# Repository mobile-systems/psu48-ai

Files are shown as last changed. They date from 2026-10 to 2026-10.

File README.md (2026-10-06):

# PSU48-800 — БП 220 В AC → 48 В DC, 800 Вт

Проект импульсного блока питания (PFC + LLC), разрабатывается в KiCad 10.

- `JOURNAL.md` — инженерный журнал (этапы, решения, изменения).
- `docs/SPEC.md` — техническое задание.
- `docs/DESIGN.md` — расчёт топологии.
- `kicad/` — проект KiCad (схема, плата, библиотеки).
- `tools/` — скрипты генерации и проверки (Python, bundled с KiCad).
- `production/` — производственные файлы (Gerber, drill, BOM, CPL, PDF).

Сборка проекта (генерация схемы/платы) и выпуск — см. журнал, этапы работ.

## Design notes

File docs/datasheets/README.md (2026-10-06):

# Справочные материалы (datasheets)

Руководства/даташиты по компонентам, использованные при проектировании PSU48-800.
Скачаны для локального хранения (сторонние ресурсы st.com/alldatasheet могут блокировать
прямой доступ или менять адреса).

| Файл | Компонент | Издатель | Источник |
|---|---|---|---|
| `UCC24624.pdf` | 2-channel LLC synchronous-rectifier controller (SOIC-8, VD≤230 В) | TI | https://www.ti.com/lit/ds/symlink/ucc24624.pdf |
| `UCC24610.pdf` | SR controller (не применён: VD max 50 В) | TI | https://www.ti.com/lit/ds/symlink/ucc24610.pdf |
| `UC3854.pdf` | Average-current-mode PFC controller | TI (UC family) | https://www.ti.com/lit/ds/symlink/uc3854.pdf |
| `L6599A_farnell.pdf` | Improved high-voltage resonant (LLC) controller; тот же TSOP-16, что L6599 | ST, копия Farnell | https://www.farnell.com/datasheets/1876813.pdf (оригинал: https://www.st.com/resource/en/datasheet/l6599a.pdf — st.com блокирует скачивание из скриптов) |
| `TinySwitch4_TNY284-290.pdf` | TNY290P offline switcher (PDIP-8C) | Power Integrations | https://www.power.com/sites/default/files/documents/tinyswitch-4_family_datasheet.pdf |
| `INA181.pdf` | Current-sense amplifier (шунт OCP, gain 20/50/100/200) | TI | https://www.ti.com/lit/ds/symlink/ina181.pdf |
| `LM393.pdf` / `LM393-N.pdf` | Dual comparator (пороги FAULT/PG) | TI | https://www.ti.com/lit/ds/symlink/lm393.pdf , https://www.ti.com/lit/ds/symlink/lm393-n.pdf |

Примечания:
- `BSC070N10NS3` (SR-переключатели, Infineon) не сохранён: infineon.com отдаёт HTML вместо PDF при автоматическом скачивании; исходники брать вручную с https://www.infineon.com/dgdl/Infineon-BSC070N10NS3-DS-v02_09-EN.pdf.
- L6599A — улучшенная ревизия L6599 с тем же назначением (резонансный полумост, 50% скважность), тот же вывод (SO-16); в схеме используется символ `Regulator_Controller:L6599`.

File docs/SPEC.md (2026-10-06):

# Техническое задание — PSU48-800

| Параметр | Значение |
|---|---|
| Входное напряжение | 176…264 В AC, 50/60 Гц (номинал 220 В) |
| Выходное напряжение | 48,0 В DC ±3 % (46,6…49,4 В) |
| Выходной ток / мощность | 0…16,7 А / 800 Вт |
| КПД | ≥ 93 % при 220 В, полной нагрузке |
| Коэффициент мощности | ≥ 0,99 при 220 В |
| THD входного тока | < 10 % |
| Пульсации выхода | ≤ 1 % (≤ 480 мВ п-п) |
| Время сохранения выхода | ≥ 20 мс при 800 Вт |
| Шина PFC | 400 В ±10 В |
| Напряжение гальванической развязки | вход — выход ≥ 3,75 кВ (усиленная изоляция, II класс) |
| Защиты | OCP, OVP, SCP (автостарт), UVLO, перегрев, разряд шины |
| Сигналы | PG (Power Good), Remote ON/OFF (TTL/сухой контакт) |
| Охлаждение | принудительное, вентилятор 12 В 60×25 мм |
| Габариты платы | 280 × 90 мм |
| Высота сборки | ≤ 40 мм (в сборе с корпусом) |
| Установка | 4 отверстия Ø3,2 под М3 |

## Состав выпуска
- Схема (иерархия, 5 листов) — PDF.
- Печатная плата — Gerber (RS-274X), Excellon drill, карта положений (CPL), BOM.
- Спецификация BOM с производителями/артикулами.

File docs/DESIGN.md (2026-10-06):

# Расчёт топологии PSU48-800

## 1. Исходные данные и баланс мощности
- Pout = 800 Вт, Vout = 48 В, Iout = 16,67 А.
- Принимаем η = 0,93 на полной нагрузке → Pin ≈ 860 Вт; ток сети при 220 В ≈ 3,9 А.
- Мощность потерь ≈ 60 Вт (PFC ≈ 20 Вт, LLC ≈ 25 Вт, выпрямитель/фильтры ≈ 15 Вт).

## 2. Входной выпрямитель и фильтр
- Предохранитель T6,3 А/250 В, MOV 14D471K, NTC 5 Ом/5 А с реле шунта (Omron G2R-1-E 12 В).
- Фильтр: X2 0,47 мкФ → дроссель общего режима 10 мГн/5 А → Y2 2×2,2 нФ → X2 0,22 мкФ.
- Мост GBU10J (10 А/600 В).
- Шина: 3 × 330 мкФ/450 В (Ø35×35, low-ESR) = 990 мкФ.
  - Запас энергии от 400 В до 340 В: E = ½·C·(400²−340²) = 22 Дж → t = 22 / 860 ≈ 25 мс ≥ 20 мс ✓.

## 3. Boost PFC (CCM, 65 кГц)
- Входной средний ток 3,9 А, пик 5,5 А; пульсации тока ΔI = 25 % Ipk = 1,4 А.
- L = Vin·D/(f·ΔI), при Vin = 311 В, D = 1 − 311/400 = 0,22:
  L = 311·0,22/(65000·1,4) ≈ 0,75 мГн → **750 мкГн**, ток насыщения ≥ 7 А (размагничивание + пульсации).
- Транзистор IPP60R099C7 (600 В, 99 мОм, TO-247): P ≈ I²·R·D/3 + переключение ≈ 8 Вт (+ потери диода).
- Диод SiC IDH10S60C (600 В, 10 А) — без обратного восстановления.
- Шунт тока UC3854: 2 × 0,22 Ом 5 Вт параллельно = 0,11 Ом; пик-напряжение 0,6 В.
- Делитель VSENSE: 400 В → 6 В (3 МОм + 51 кОм), фильтр 100 нФ.
- Осциллятор UC3854: Rt = 6,8 кОм? → f ≈ 65 кГц (Rosc = 659/Vosc... берётся 6,8 кОм), Ct = 3,3 нФ.
- Ограничение пускового тока, плавный пуск: Css = 100 нФ.

## 4. LLC полумост (преобразователь DC/DC)
### Преобразование
- Шина 400 В, полумост → амплитуда на первичке ±200 В.
- Трансформатор: Np : Ns(половина) = 4 : 1, выводы: первичка 40 витков (лitz 2×0,1), вторичка 2 × 10 витков (шинка), центральный отвод.
- Vsec(половина) = 200/4 = 50 В → после синхронного выпрямления ≈ 48 В при M = 0,96…1,0 (работа у резонанса).

### Резонансный контур
- Нагрузка, отражённая: Rac ≈ V1(осн)² / Ppri; V1(осн) = (4/π)·200/√2 = 180 В, Ppri ≈ 860 Вт → Rac ≈ 38 Ом.
- Выбираем: **Lr = 40 мкГн, Cr = 82 нФ (3 × 27 нФ/630 В параллельно)** → f0 = 1/(2π√(Lr·Cr)) ≈ **88 кГц**.
- Характерное сопротивление Zr = √(Lr/Cr) = 22 Ом → Q = Zr/Rac ≈ 0,58 (в допустимом диапазоне 0,3…0,7).
- Индуктивность намагничивания Lm = 4 × Lr ≈ 160 мкГн (зазор по расчёту на EE35).
- Диапазон регулировки: fmax ≈ 130 кГц (холостой ход), fmin ≈ 50 кГц (старт/перегрузка), M(fmin) ≈ 1,3.
- Транзисторы полумоста: 2 × IPP60R099C7 (как в PFC — унификация).
- Резонансный конденсатор: ток ≈ 4,3 А действ., 3 × 27 нФ → 1,4 А на конденсатор ✓.

### Синхронный выпрямитель и выход
- 2 ключа по схеме с центральным отводом, каждый — 2 × BSC070N10NS3 (100 В, 7 мОм, TDSON-8) параллельно; I²R ≈ 0,5 Вт на ключ.
- Управление — 1 × UCC24624 (двухканальный SR-контроллер для LLC, чувствительные VD-выводы на 230 В), по напряжению сток-исток.
- Выходной фильтр: 4 × 470 мкФ/63 В (105 °C, low-ESR) + керамика 10 × 10 мкФ/100 В; расчёт пульсаций при f = 176 кГц на выходе ≈ 30 мВ п-п ✓.
- TVS 1,5SMC58A, разрядный/преднагрузочный резистор 68 кОм 5 Вт.

### Управление
- Регулировка по напряжению: TL431 (опорное 2,5 В, делитель 48 В → 2,5 В) → оптрон PC817 → вход FB L6599.
- Токовая защита: шунт 3 мОм на возврате вторички → INA181A2 (×50) → компаратор LM393 → SD L6599 (порог ≈ 19 А).
- OVP: компаратор LM393 (опора 5,0 В на делителе выхода) → SD.

## 5. Вспомогательный источник
- Flyback на TNY290PG от шины 400 В (схема с общим возвратом), EE16, 65 кГц.
- Обмотки: +15 В / 0,6 А (первичная обмотка — питание UC3854, L6599, реле, вентилятор через L7812 → 12 В) и изолированная +15 В / 0,3 А (вторичная обмотка — питание UCC24624).
- Обратная связь по PC817 (цикл по напряжению + ограничение тока обмотки).

## 6. Тепловой баланс и охлаждение
- ≈ 60 Вт рассеивания: PFC-транзистор ≈ 8 Вт, LLC ≈ 10 Вт, диод PFC ≈ 5 Вт, SR ≈ 3 Вт, мост/шунты/EC ≈ 15 Вт, трансформаторы ≈ 15 Вт.
- Решение: линейка TO-247 PFC/LLC на общем алюминиевом профиле (высота ≤ 25 мм), обдув вентилятором 60×25 мм с торца корпуса; площадь радиатора ≈ 150 см² при ΔT ≈ 40 К достаточно.

## 7. Размещение на плате (концепция)
Слева направо: вход AC + фильтр → мост + шина (верхний ряд конденсаторов) → PFC (дроссель, ключ, диод) → полумост LLC + резонанс → трансформер EE35 → вторичный выпрямитель + выходные конденсаторы → выходные клеммы. Вспомогательный flyback и логика управления — вдоль нижнего края. Силовой ток идёт слева направо по «полосе» шириной ≥ 8 мм, возврат — нижняя медная заливка.

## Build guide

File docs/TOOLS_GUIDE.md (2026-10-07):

# Руководство по инструментам (tools/) PSU48

Скрипты в `tools/` генерируют и проверяют проект PSU48 (KiCad 10) "из текста":
схема, библиотека, плата, размещение и (экспериментально) трассировка.
Часть кода универсальна и пригодна для других независимых проектов; часть —
жёстко привязана к конфигурации `tools/sch_data.py`. Ниже — реестр, порядок
работы, способ переноса на новый проект и ограничения.

---

## 1. Окружение

- Windows, KiCad **10.0** (`C:/Program Files/KiCad/10.0`).
- Python берётся из дистрибутива KiCad:
  `"C:/Program Files/KiCad/10.0/bin/python.exe"` (свой системный Python не требуется).
- Все скрипты запускаются из каталога `tools/` (они импортируют друг друга через
  относительные имена).
- CLI KiCad: `"C:/Program Files/KiCad/10.0/bin/kicad-cli.exe"`.
- Единица хранения данных — **S-выражение** (S-expr). Парсинг/сериализация
  полностью вынесены в `sexp.py`.

---

## 2. Реестр скриптов

| Файл | Роль | Переиспользуемость |
|---|---|---|
| `sexp.py` | Парсер/сериализатор S-expr (KiCad-совместимый), helpers `find/findall/unq/Q/num` | Полностью универсален |
| `kilib.py` | Чтение `.kicad_sym`/`.pretty/*.kicad_mod`, геометрия выводов, встраивание symbol в `lib_symbols` | Универсален (слой библиотек KiCad) |
| `sch_data.py` | **Конфигурация проекта**: листы, элементы, сети, клеммы питания, отверстия | Только psu48 (заменить целиком) |
| `schgen.py` | Генератор `.kicad_sch` (корень + листы) из `sch_data`; пишет `.kicad_pro` | Ядро универсально, питается конфигом |
| `verify.py` | Экспорт netlist (`kicad-cli sch export netlist`) + сверка с `sch_data` | Универсален (нужен конфиг) |
| `qa.py` | Проверка корпусов: совпадение падов с пинами схемы, геометрия | Полезен для проверки библиотек |
| `mklib.py` | Сборка проектной библиотеки `kicad/psu48_lib.kicad_sym` и `kicad/psu48.pretty/*` | Настройка под проект (списки пар) |
| `pcbgen.py` | Генерация `.kicad_pcb` (280×90, корпуса из библиотек, назначение сетей) + размещение | Каркас универсален, геометрия/якоря — под psu48 |
| `router.py` | Экспериментальная автотрассировка (2 слоя, A*, треки/виа) — **β** | Ядро универсально; стили шин/порядок — конфиг |
| `dump_pins.py` | Отладка: списки пинов символов `Device:R` и пр. | Универсальный отладочный |
| `peek_symbol.py` | Отладка: печать фрагмента `.kicad_sym` | Универсальный отладочный |

---

## 3. Порядок работы (workflow)

Оптимальный порядок для нового проекта:

1. **Библиотеки** — `mklib.py` (если используются свои символы/корпуса).
2. **Схема** — `schgen.py`: пишет `kicad/<project>.kicad_sch`,
   `kicad/<sheet>.kicad_sch`, `kicad/<project>.kicad_pro`.
3. **Проверка схемы** — `verify.py` (сверка pin↔net против конфига) и
   `kicad-cli sch erc <root>.kicad_sch -o out.rpt`.
4. **Контроль корпусов** — `qa.py`.
5. **Плата + размещение** — `pcbgen.py`: пишет `kicad/<project>.kicad_pcb`.
6. **DRC посадочных** — `kicad-cli pcb drc ... --severity-all`.
7. **Трассировка (экспериментально)** — `router.py` (дописывает треки/виа в ту же плату).
8. **Финальный DRC**, затем вывод Gerber/Drill/BOM/CPL/PDF через `kicad-cli`.

Типовые команды (из `tools/`):

```bash
PY="C:/Program Files/KiCad/10.0/bin/python.exe"
"$PY" mklib.py
"$PY" schgen.py
"$PY" verify.py
"$PY" qa.py
"$PY" pcbgen.py
"$PY" router.py            # β
CLI="C:/Program Files/KiCad/10.0/bin/kicad-cli.exe"
"$CLI" pcb drc ../kicad/psu48.kicad_pcb -o C:/tmp/pcbdrc.rpt --severity-all
```

---

## 4. Адаптация под новый проект

Минимально заменяется конфиг `sch_data.py`; имя проекта и параметры
разбросаны в заголовках скриптов.

### 4.1 `sch_data.py`
- `PROJECT`, `ROOT_TITLE`, `REV`, `DATE` — имя и шапка.
- `POWER_TERMS` — глобальные (клеммные) сети.
- `SHEETS` — список листов с элементами `{"id", "title", "entries": [{ref,
  fp, val, nets, at, bb, pinmap, ...}]}`. Это **расширяемая спецификация**
  схемы: по ней schgen рисует лист, verify сверяет, pcbgen ставит корпуса.
- `ROOT_HOLES` — монтажные отверстия.
- Геометрия размещения (`X0/Y0/COL_GAP/...`) — разметка листа.

### 4.2 `pcbgen.py`
- `BOARD_W`, `BOARD_H` — габариты платы.
- `PREFER`, `GROUP_ANCHOR`, `REGION_BOARD`, `HOLE_POS`, `MARGIN`, `PACK_STEP` —
  стратегия размещения (якоря структур/листов, допуски).
- `fp_path()` — откуда брать `.kicad_mod` (проектная `psu48.pretty` или
  стандартная библиотека KiCad).
- `net_name()` — правила "локальная/глобальная" сеть в имени платы.

### 4.3 `router.py`
- `net_style(net)` — ширина/класс по имени сети (OUT/HV/PWR/SIG).
- Порядок трассировки `route_key()` (класс → число падов).
- Параметры через env (см. ниже).

---

## 5. Ограничения

### Общие
- Скрипты рассчитаны на одну плату/один уровень иерархии схемы; символы
  только из `.kicad_sym` (KiCad 10 S-expr), не Symbol-Library-Table v7.
- Никакой GUI-проверки: корректность подтверждается только `kicad-cli
  drc/erc` + `verify.py`.
- Формат вывода заточен под **KiCad 10** (см. §6).

### Роутер (`router.py`) — экспериментальный
- Сетка трассировки — **0.2 мм**; минимальный эффективный зазор —
  `ROUTE_CL≥0.2`. Из-за квантования невозможно провести трассу к выводу
  SOIC-шага 1.27 мм с чистым DRC — зазор между соседними контактными
  площадками закрывается кольцами запаса. Сигнальные сети в плотных
  кластерах могут оставаться неразведёнными.
- Только **2 сигнальных слоя**, A* с 4-соседними переходами, виа 1.2/0.6 мм.
- Многослойная связность падает при большом числе падов у сети (манхэттенский
  поиск по сетке — не промышленный роутер; для высокой заполненности нужен
  fanout/эскейп-роутинг).
- Ядро **не проверяет** реальный DRC сам; контроль — внешний `kicad-cli pcb drc`.
- Режимы через переменные окружения:
  - `PSU_STEP` — шаг сетки, мм (по умолчанию 0.2; 0.1 — заметно медленнее);
  - `PSU_SIGW` — ширина сигнальных трасс (0.3);
  - `PSU_CL` — зазор трассировки (0.25);
  - `PSU_RCAP` — множитель узости колец запаса (0..1; 0 открывает каналы и
    может нарушать DRC).
- Текущее состояние: большинство силовых сетей проводятся; сигнальные
  сети между выводами мелких корпусов — предмет доработки.

### `pcbgen.py`
- Размещение строится структурно (функциональные группы листов), а не
  по соединениям; auto-оптимизатора нет.
- Сети "склеиваются" по правилам `net_sheets_map()`: локальные сети листа
  получают префикс `Лист/Сеть` — решение специфично для иерархии проекта.

### `schgen.py`
- Переиспользуемо как движок "S-expr → лист", но разметка листа
  (`PAPER_LIMITS`, перенос при `Overflow`) отражает стиль psu48.

---

## 6. Особенности KiCad 10, зафиксированные в проекте

Эти детали важны при генерации любых файлов для KiCad 10:

- **Треки и виа** в `.kicad_pcb` используют атрибут `(uuid "...")`, а **не**
  `(tstamp ...)` — иначе "Failed to load board: Expecting ')'".
- Внутри `(segment ...)`/`(via ...)` сеть пишется **только кодом** без имени:
  `(net 4)`, а не `(net 4 "+48V")` (в узлах сетей платы — наоборот, и код, и имя).
- Порядок критичных узлов платы: `(kicad_pcb (version) (generator)
  (general) (paper) (title_block) (layers ...) (setup ...) (net ...)`*
  затем корпуса, затем треки/виа, в конце `(embedded_fonts no)`.
- Чисел с ведущими пробелами не допускается; числа печатаются через
  `sexp.num()` (максимум 6 знаков, без хвостовых нулей).
- Кодировка файлов — UTF-8, переводы строк `\n` (не `\r\n`).
- `sexp.py` сохраняет точный исходный текст атомов: строки остаются в
  кавычках (`Raw`), поэтому round-trip идентичен исходнику.

---

## 7. Как понять и изменить внутреннюю модель

- **Узел** в `sexp.py` — обычный Python-список: `["kicad_pcb",
  ["layers", ...]]`. `dumps()` сам добавляет скобки и отступы.
- `Raw("...")` — "сырое" значение (например, `'"F.Cu"'`), его нельзя
  редактировать как строку Python.
- Порядок и обработку данных смотри: `sch_data.py` (спека) →
  `schgen.py`/`verify.py` (схема) → `pcbgen.py` (плата) → `router.py`
  (трассы). Каждый следующий потребляет предыдущий через общий конфиг.

---

## 8. Итог для переноса

| Что нужно | Где править |
|---|---|
| Имя проекта / шапка | `sch_data.py` |
| Список листов и элементов | `sch_data.py` (секции `SHEETS`) |
| Глобальные сети | `sch_data.py` (`POWER_TERMS`) |
| Монтажные отверстия | `sch_data.py` (`ROOT_HOLES`) + `pcbgen.HOLE_POS` |
| Габариты платы | `pcbgen.BOARD_W/BOARD_H` |
| Стратегия размещения | `pcbgen.PREFER/GROUP_ANCHOR/REGION_BOARD` |
| Ширины/приоритеты трасс | `router.net_style()/route_key()` |
| Зажим точности роутера | env `PSU_STEP/PSU_SIGW/PSU_CL/PSU_RCAP` |

Универсальные блоки (`sexp.py`, `kilib.py`, ядро `schgen/verify/pcbgen/router`)
берутся без изменений; проектная спецификация целиком сосредоточена в
`sch_data.py` + нескольких таблицах констант в заголовках генераторов.

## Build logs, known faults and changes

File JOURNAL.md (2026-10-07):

# Инженерный журнал проекта «PSU48-800»

**Изделие:** импульсный блок питания 220 В AC → 48 В DC, 800 Вт
**Формат:** проект KiCad 10, ПП 280 × 90 мм, высота корпуса 40 мм
**Ведётся:** с 2026-10-06

---

## 2026-10-06 — Этап 0. Инициализация

### Окружение
- Windows 11 Pro, KiCad 10.0.6 (`C:\Program Files\KiCad\10.0\bin\kicad-cli.exe`).
- git 2.56.0, Python 3.11.5 (в комплекте KiCad — используется для скриптов генерации).
- Репозиторий git инициализирован в корне проекта; все изменения коммитятся с пояснениями.
- Рабочая папка: `C:\Users\alexa\workspace\psu48-ai`. Все артефакты — только в ней.

### Принятая архитектура (вариант, выбранный сразу)

Для 800 Вт с высоким КПД и PF ≥ 0,99 применяется классическая двухступенчатая схема:

1. **Входной тракт**: предохранитель, MOV, NTC + реле шунта, двух-каскадный симметричный фильтр помех (X2/Y2, дроссель общего режима), мостовой выпрямитель.
2. **PFC (коррекция коэффициента мощности)** — boost в непрерывном режиме (CCM), 65 кГц, выходное напряжение шины **400 В**. Контроллер — **UC3854GN**. Мощные элементы: IPP60R099C7 (600 В, 99 мОм), диод-шоттки SiC IDH10S60C, дроссель 750 мкГн/5,5 А.
3. **DC/DC** — резонансный **LLC полумост**, ~88 кГц резонанс, трансформатор EE35 с раздельной резонансной индуктивностью, синхронный выпрямитель на вторичной стороне (4 × BSC070N10NS3, контроллеры UCC24610 ×2), выход 48 В / 16,7 А. Контроллер — **L6599D**.
4. **Вспомогательный источник** — flyback на TNY290PG от шины 400 В: +15 В (первичная обмотка, питание контроллеров и вентилятора через L7812) и изолированная обмотка +15 В (вторичная сторона, питание SR-контроллеров).
5. **Защиты и сигнализация**: OCP (шунт 3 мОм + INA181 + LM393), OVP (TL431/компаратор), UVLO, PG, Remote ON/OFF, разряд шины.

### Компромиссы, ограничения корпуса 40 мм
- Максимальная высота элементов — 35 мм (конденсаторы шины Ø35, трансформатор EE35 ≈ 30 мм).
- Теплоотвод: 800 Вт при η ≈ 93 % → ≈ 60 Вт рассеивания; заложено охлаждение принудительное (вентилятор 60×25 в корпусе), мощные транзисторы — в линейку с общим алюминиевым радиатором/полосой.
- Плата 280 × 90 мм, 2 слоя, медная заливка под силовые цепи (толщина меди 2 oz в силовых зонах — рекомендация для технолога).

### План работ (этапы, каждый — отдельный коммит)
1. Документация: ТЗ, расчёт топологии, журнал (this commit).
2. Средства генерации: сепаратор s-expr, загрузчик библиотек символов, генератор иерархической схемы.
3. Схема: 5 листов + собственная библиотека символов, проверка ERC и сверка нетлиста со спецификацией соединений.
4. Библиотеки footprint + генерация PCB: контур 280×90, размещение.
5. Маршрутизация, зоны заливки, DRC.
6. Выпуск производственных файлов: Gerber/Drill/BOM/CPL/PDF.

### Идеи / заметки
- Все соединения в схеме задаются декларативно (карта «вывод → имя цепи»), генератор расставляет символы и подписи. Это позволяет скриптом **проверять нетлист против задуманной карты** — защита от ошибок «метка не попала на вывод».
- Глобальные метки — для цепей, выходящих за границы листа; локальные — внутри листа.
- PWR_FLAG на всех силовых цепях для чистого ERC.
- Резонансный контур LLC: Lr = 40 мкГн, Cr = 82 нФ (3×27 нФ), Lm ≈ 160 мкГн, f0 ≈ 88 кГц, Q ≈ 0,6 — расчёт подробно в `docs/DESIGN.md`.

---

---

## 2026-10-06 — Этап 3. Схема: 5 листов, генератор, ERC, сверка нетлиста

### Реализовано
- `tools/sch_data.py` — декларативная спецификация: 5 листов (`01_ac_input`…`05_ctrl`), все компоненты с картами «вывод → цепь», константы раскладки (STUB=5.08, BEND=2.54, ROW_GAP=5.08, COL_GAP=20.32, GAP=10.16, X0/Y0), POWER_TERMS.
- `tools/schgen.py` — генератор файлов `.kicad_sch` (root A4 + листы A3/A2 при переполнении) и `psu48.kicad_pro`; терминаторы-штабели, L-изгибы, локальные/глобальные метки, PWR_FLAG, `no_connect`, instance-пути.
- `tools/verify.py` — сверка нетлиста `kicad-cli sch export netlist` против карт `sch_data` (445 выводов / 97 цепей — PASS).
- `tools/qa.py` — геометрический контроль текстов/символов по файлу схемы.

### Ошибки, найденные доводкой и исправленные
- **Sub-symbol naming**: символы, использующие `(extends …)` (напр. `Comparator:LM393` ← `LM2903`), при внедрении в `lib_symbols` должны переименовывать подстили в `<имя>_<unit>_<style>`; иначе KiCad не грузит файл («Failed to load schematic»). Исправлено в `kilib.merge_derived`.
- **Wires**: KiCad допускает ТОЛЬКО двухточечные `(wire (pts …))`; трёхточечные (изгиб) приводят к ошибке загрузки. Изгиб теперь — два сегмента.
- **Дубли UUID**: у двух PWR_FLAG на одном листе совпадали ключи `sheet:None:1` → дублировались `(uuid …)` символа и пинов. Ключи флагов переведены на счётчик `flg`.
- **`circle` в символьной графике**: KiCad 10 хранит `(radius …)` вместо `(end …)` — `bbox_of` теперь понимает оба.
- **Footprint**: `Connector_TerminalBlock:TerminalBlock_bornier-2` не существует в KiCad 10 (библиотека переименована) → `TerminalBlock:TerminalBlock_MaiXu_MX126-5.0-02P_1x02_P5.00mm`.
- **ERC вредные 4 → 0**: 
  - `SR_SYNC` (UCC24610 pin 1, Input) не имел драйвера — по даташиту при неиспользуемом синхросинтезе пин подключают к GND; U302/U303 pin 1 → GND48 (*сверить с datasheet*).
  - остальные (пороговые входы компараторов — не Pins, а internal, сеть лишь из пассивов) — рассмотрено, свойств нет.
- **Overflow A3→A2**: ширина строки вычислялась до правки условия переноса (не учитывала `wr` и межэлементный зазор) — исправлено; `03_llc` закономерно занял A2.

### Проверки (все PASS)
1. Каждый лист и root независимо открываются `kicad-cli sch export netlist` (0 компонентов не потеряно; листы грузятся и отдельно).
2. `kicad-cli sch erc` по всему проекту: **0 ошибок, 0 предупреждений**.
3. `verify.py`: нетлист совпадает со спецификацией на 445 выводах / 97 цепях.
4. `qa.py`: наложений текстов/символов не выявлено (одно касание двух меток одной цепи `HN` с зазором 0.27 мм — косметика).

### Решения и допущения (сверить с datasheet)
- UCC24610: SYNC н/и → GND48; работа в режиме удержания времени (TON), без внешней синхронизации.
- L6599 RFMIN: оптопара регулятора параллельно R_min (f увеличивается при FB) — взято из классической топологии; полярность подтвердить по datasheet.
- ERC-фильтры «не включены»: нетлист — прямое зеркало спецификации.

### Компоненты листа (итог)
`01_ac_input` 18, `02_pfc` 43, `03_llc` 66, `04_aux` 27, `05_ctrl` 26, root-крепеж H1–H4 (MountingHole 3.2 mm M3) — всего ~180 поз. + символы питания.

### Уточнения по даташитам (websearch-верификация; правки внесены)
- **L6599 RFmin (pin 4)** — даташит ST подтверждает топологию: пин отдаёт точное опорное 2 В; три ветви: RFmin→GND (мин. частота), RFmax→коллектор оптрона (макс. частота), R-C серия Css/Rss (мягкий старт). Чем выше ток с пина, тем выше частота → при росте Vout частота повышается, Vout падает — полярность ОС подтверждена.
  - R309 20k (RFmin) ✓; добавлен **R328 4.7k (RFmax)** последовательно коллектору U306 → RFmin; **R308 100k** переведён с некорректной цепи на мягкий старт (LLC_CSS→LLC_FB).
  - Пин 2 и 13 L6599 — **N.C.**; удалены R308-старая ветка и C303 (намеренная «цепь задержки» на N.C. — ошибка).
- **UCC24610 НЕ применим при 48 В**: VD (сток-SR) номинально максимум 50 В; вторичная обмотка LLC на 48 В даёт ~2×48=96 В на стоке SR. Также SYNC, «подвязанный к GND», удерживал бы GATE выключенным (SR не работал бы).
  → **замена на UCC24624 (TI)**: двухканальный SR-контроллер LLC, VD до 230 В, reference-design 48 В/550 Вт (UCC256302+UCC24624). Один корпус вместо двух. Питание VDD (+15VS, <24.75 В — прямое подключение), REG байпас 2.2 мкФ, VSS к GND48 («не оставлять открытым»).
  - Символ `psu48_lib:UCC24624` (SOIC-8, 1=VG1 2=PGND 3=REG 4=VD1 5=VSS 6=VD2 7=VDD 8=VG2) добавлен в mklib.
  - Схема: G_SR1/G_SR2 (по 2 FET), VD1/VD2=SEC_A/SEC_B, удалены U303/R314/R315/C314 (артефакты UCC24610 TON/SYNC).
- Повторная проверка после правок: verify 433 вывода OK, ERC 0/0, qa чисто (одно касание меток HN с зазором 0.27 мм — косметика).

### Справочные материалы (docs/datasheets/)
- Пользователь попросил хранить найденные PDF/manuals в `docs/`. Скачано 8 даташитов:
  UCC24624, UCC24610, UC3854, L6599A (копия Farnell — st.com блокирует скриптовое скачивание),
  TinySwitch-4 TNY284–290, INA181, LM393/LM393-N. Список и источники — `docs/datasheets/README.md`.
- BSC070N10NS3 (Infineon) не скачан автоматически (отдаёт HTML); ссылка в README.

---

## 2026-10-07 — Этап 4 (подготовка PCB): генерация платы, размещение, DRC

### Найден и устранён реальный дефект схемы (коллизия локальных меток)
- Проверка имён локальных сетей по листам (для PCB-нетлиста) выявила **ошибочное склеивание меток между листами**:
  - `SEC_A` — на листе **03** (вторичка LLC: T301, Q310–Q313, U302) и на листе **04** (вторичка aux‑flyback: T401 pin5, D404 pin2) — через метку «SEC_A» вторичная 48‑В обмотка LLC электрически соединялась бы с вторичной 15‑В обмоткой aux. **→ переименовано в `AUX_SEC`.**
  - `LED_A` — на листе **03** (катод оптрона ОС U306) и на листе **05** (индикатор LED501) — через метку «LED_A» катод LED16 соединялся бы с током индикатора (несогласованная ветвление ОС). **→ переименовано в `STATUS_LED`.**
- Проверка после правки: локальных коллизий нет; кросс‑листовые цепи (кроме POWER_TERMS) только намеренные: `ISENSE_48` (03/05, шунт→INA181), `LLC_LINE` (03/05, оптропарная ОС MPF), `PFC_EN` (02→03). verify **433 вывода / 99 цепей OK**, ERC **0/0**, qa — без новых наложений.

### `tools/pcbgen.py` — генератор `kicad/psu48.kicad_pcb` (KiCad 10)
- kicad-cli **не умеет создавать PCB и импортировать нетлист** (команды только drc/export/import/render/upgrade), поэтому плата пишется S-выражением: заголовок `(version 20260206)`, слои/setup — по эталону пустой платы из `pcbnew.CreateEmptyBoard()`, таблица `(net 0 "«)(net N "имя")`, футиринты встраиваются из `.kicad_mod` с картинкой/падами/нетом по номеру пина, контур 280×90 — `gr_line` на Edge.Cuts, H1–H4 по углам.
- **Имена сетей в PCB полностью совпадают с нетлистом**: локальные → `SHEET/NAME` (как в netlist/verify.py), глобальные/POWER_TERMS → короткое имя.
- **Размещение**: площадь корпусов ≈ 14 300 мм² при доске 25 200 мм² (Σ с учётом корпусов, а не только пад — иначе коротят). Упаковщик: крупные первыми (меньше фрагментации), у каждой позиции «якорь» функциональной группы → сначала точный слот, затем спиральный поиск вокруг якоря, затем общий свип; монтажные отверстия — препятствия. Ошибка «no free spot» при данном наборе не возникает.

### Ключевые баги геометрии, найденные через DRC
1. **Форма `(at x y ROT)`: поворот в KiCad — по часовой стрелке.** Мой первый `abs_rect` крутил против часовой → каждые J301/J501 (ROT 90) резервировали не ту область → короткие цепи «HN×LED_A», «GND48×PFC_VS» и пр. Исправлено: `rot = −radians(...)`.
2. **Ориджин футиринта ≠ центру bbox.** Пады многих THT-корпусов (TerminalBlock, PinHeader, DIP) живут далеко от центра симметрии; упаковщик резервировал «центрированную» рамку → пады выкалывались за её край → реальные короткие цепи. Теперь считается истинный `abs_rect` от локального `(min, max)` с доворотом углов.
3. **`fp_circle`**: у KiCad окружность — `(center)/(end)` (точка на окружности), а не радиус; прошлая версия читала радиус как координату end → у отверстий/корпусов courtyard по Y недооценивался (у H1 3.45×1.6 вместо 6.9×6.9). Исправлено через `hypot(end−center)`.
4. **`fp_text`**: бокс текста — не точка, а ≈ полразмера шрифта вокруг якоря (+0.15) → меньше ложных «Silkscreen clipped by solder mask».

### DRC (kicad-cli pcb drc)
- **0 ошибок уровня copper**: нет коротких замыканий, нарушений зазора 0.2 мм, hole‑clearance, маски. Пас.
- Остались **предупреждения silk** (≈199 silk_overlap + ≈126 silk_over_copper) — наложени графики шелкографии соседних корпусов/текста; косметика, не влияет на электрику.
- 335 «unconnected pads» — вывода с цепями но без меди (маршрутизация на этапе 5) + неиспользуемые пины (запасные контакты реле K101, QFN‑thermal, механические). Нормально до разводки.
- lib_footprint_mismatch появлялся **только у повёрнутых на 90°** разъёмов J301/J501 — артефакт сверки этой версии KiCad; повороты сняты (ROT 0) → предупреждений нет. Геометрия корпусов идентична библиотеке (проверено структурным diff).
- 2×`MountingHole` в углах учтены как препятствия; контур и края чистые.

### Заметки на следующий этап (маршрутизация)
- Проверить соответствие посадочного места/нумерации выводов у малогабаритных символов (U503 TL431). Проверить сети полей: 2 слоя, заливки GND/PGND_OUT/VBUS400/+48V.
- Из предупреждений DRC отфильтровать silk (footer «ignore»); добиваться 0 ошибок — достигнуто.

---

## 2026-10-07 — Этап 5 (начало): автотрассировка `tools/router.py`

### Статус
Экспериментальная. Плата в рабочем дереве содержит результат последнего прогона
(712 сегментов / 595 виа); файл **валиден и грузится KiCad**, но DRC **чистым не
является** (см. «Проверки»). Основные проблемы диагностированы; финальный
рефакторинг модели занятости **начат и не завершён** (код в `router.py`
компилируется, но с промежуточными остатками `trackF/trackB`).

### Валидность кикадовского вывода (решено)
- KiCad 10 в `(segment …)`/`(via …)` принимает сеть **только кодом без имени**
  `(net 66)`, а не `(net 4 "+48V")`, и атрибут **`(uuid …)`, а не `(tstamp …)`** —
  иначе `Failed to load board: Expecting ')'`. Оба фикса в `router.py`
  (эталон синтаксиса — demo-плата CM5_MINIMA + файл от pcbnew + пустая плата
  `pcbnew.CreateEmptyBoard()`). После правок файл читается, DRC запускается.

### Устранено по ходу доводки
- Убран `carve`, эрозировавший занятость ранее проложенных широких треков →
  короткие замыкания.
- Порядок разводки: `pending` был `set` (терялся приоритет — +48V разводились
  раньше сигнальных → низкая разводимость); теперь цикл по упорядоченному списку.
- Инфлейт падов был не зависим от ширины трассы (0.4 мм) → широкие трассы
  налезали на чужие пады; введены ширино-зависимые маски `masks[r]` и
  виа-маска `vm_all` (пады + пояс воль via).
- `prep_route` (зануление собственных падов в маске), `own_reuse` (повторное
  использование своих проводников в многосвязных сетях).

### Результаты прогонов (routed / DRC)
- `PSU_RCAP=0.0` (узкие кольца): **86/89** сетей разведено (+48V не лезет,
  `02_pfc/PFC_MULT`, `03_llc/LLC_DIS`, `04_aux/AUX_SEC`) — но узкие кольца
  нарушают зазоры.
- `PSU_RCAP=1.0` (запас): ~59/63 — почти все силовые, но сигнальные в
  SMD-кластерах не проходят.
- Последний DRC рабочем дереве (1791): clearance 499, **shorting_items 199**,
  **holes_co_located 199**, **tracks_crossing 143**, unconnected 169, hole_to_hole 95,
  track_dangling 58, copper_sliver 8, + silk (косметика).

### Диагнозы (корни оставшихся ошибок)
1. **`holes_co_located` ≈199** — `split_path` при переходе слоёв генерирует **два
   виа в одной точке**; нужен один `(i,j)` на переход.
2. **shorting / tracks_crossing ≈199** — зазор трасса-трасса считался по своей
   ширине; для разных классов требуется **симметричный парный зазор
   `(wA + wB)/2 + CL`** — иначе узкие трассы пересекают/касаются широких
   (+48V 2.5 мм и др.), даже когда кольца падов валидны.
3. **Квантование сетки 0.2 мм** — SOIC-шаг 1.27 мм: зазор между соседними падами
   закрывается кольцами запаса; сигнальные сети в плотных кластерах не выходят.

### Решение (спроектировано, НЕ реализовано)
Замена `trackF/trackB` на **per-routing-class маски** `tm[cls]` (треки) и
`vm2[cls]` (виа), обновляемые инкрементально при прокладке пути ширины `wl`
для всех классов `w(cls) ≤ wl`: радиус `tm = (w_cls + wl)/2 + CL`,
`vm2 = (VIA_SIZE + wl)/2 + CL`; `mm` (чужие пады) и `own_reuse` сохраняются;
`via_free` дополнительно = `vm_all` и `vm2[live_cls]`. Плюс фикс `split_path`
(один виа на переход). Это должно снять и «пересечения ширин», и «виа на проводнике».

### Параметризация (env)
`PSU_STEP` (0.2), `PSU_SIGW` (0.3), `PSU_CL` (0.25), `PSU_RCAP` (0..1),`PAD_CAP`
не используются — для скан-прогонов по конфигурациям без правки кода.

### Документация
- `docs/TOOLS_GUIDE.md` — руководство по переиспользованию `tools/` в других
  проектах: реестр скриптов, порядок запуска, способ адаптации конфигурации,
  ограничения (роутер β: 2 слоя, сетка 0.2 мм, два уровня A*), особенности
  синтаксиса KiCad 10.

### На следующий этап
- Дописать `tm`/`vm2` + одиночный виа в `split_path`; прогон → DRC; скан
  конфигов (STEP, SIGW, CL, RCAP); создание медных зон GND/GND48/+48V/VBUS400/
  VRECT; проверить U503 (TL431DBV, пады 1/2 без сети — несоответствие
  footprint/symbol).

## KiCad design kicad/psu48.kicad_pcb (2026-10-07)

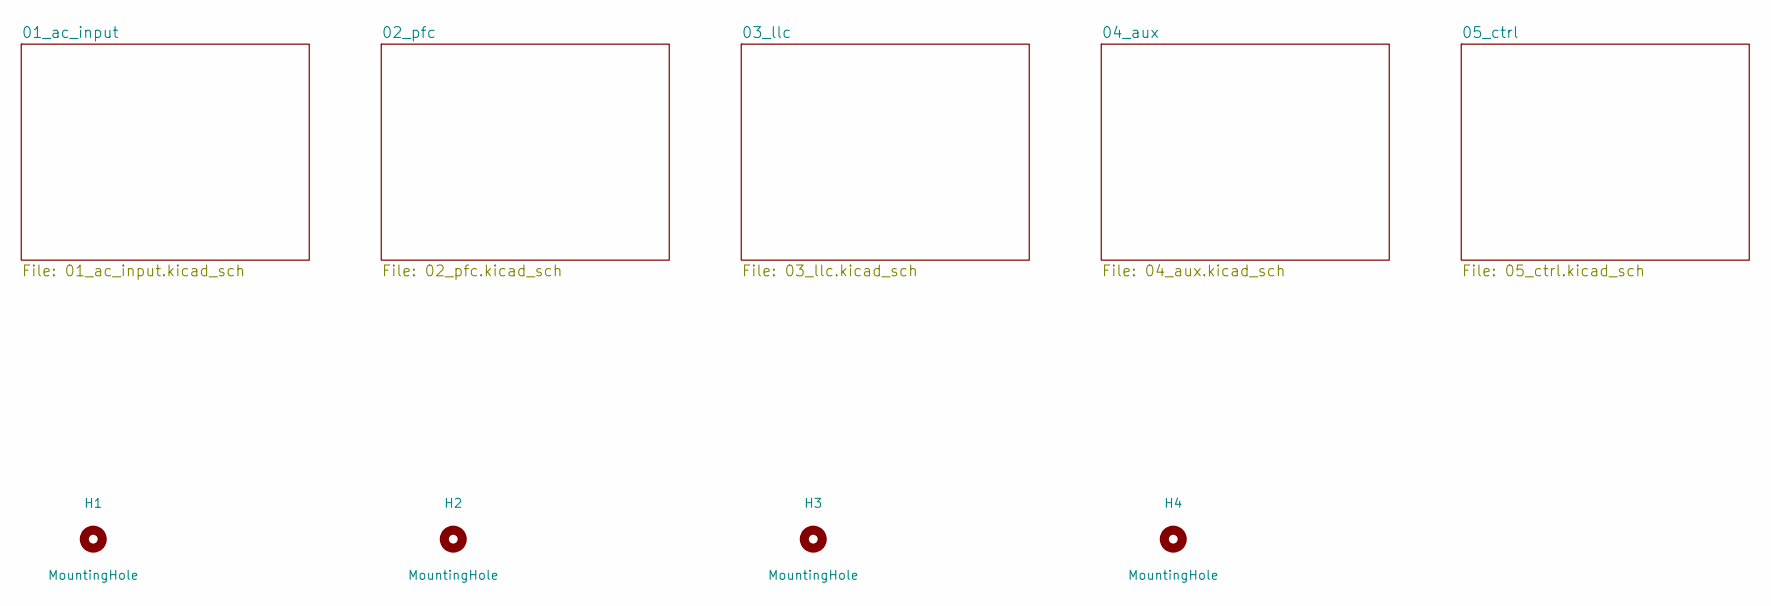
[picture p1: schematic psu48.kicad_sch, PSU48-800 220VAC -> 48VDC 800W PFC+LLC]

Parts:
H1, H2, H3, H4: MountingHole; MountingHole_3.2mm_M3

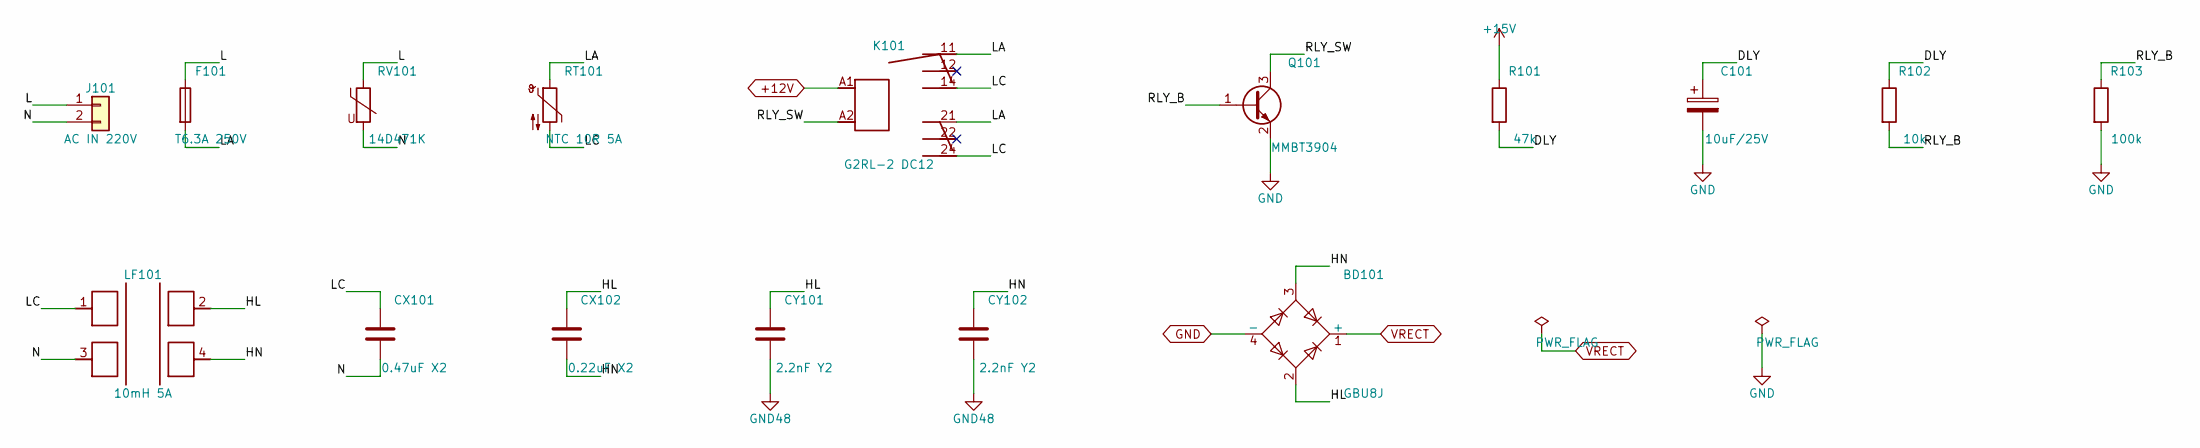
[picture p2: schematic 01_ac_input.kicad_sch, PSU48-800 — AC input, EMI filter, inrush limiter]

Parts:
BD101: GBU8J; Diode_Bridge_Vishay_GBU
C101: 10uF/25V; CP_Radial_D5.0mm_P2.50mm
CX101: 0.47uF X2; C_Rect_L27.0mm_W11.0mm_P22.00mm
CX102: 0.22uF X2; C_Rect_L16.5mm_W5.0mm_P15.00mm_MKT
CY101, CY102: 2.2nF Y2; C_Disc_D10.5mm_W5.0mm_P7.50mm
F101: T6.3A 250V; Fuseholder_Clip-5x20mm_Littelfuse_111_Inline_P20.00x5.00mm_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
J101: AC IN 220V; TerminalBlock_MaiXu_MX126-5.0-02P_1x02_P5.00mm
K101: G2RL-2 DC12; Relay_DPDT_Omron_G2RL-2
LF101: 10mH 5A; CMChoke_25x20_P20x10
Q101: MMBT3904; SOT-23
R101: 47k; R_0805_2012Metric
R102: 10k; R_0805_2012Metric
R103: 100k; R_0805_2012Metric
RT101: NTC 10R 5A; NTC_D11.0mm_P5.00mm
RV101: 14D471K; RV_Disc_D15.5mm_W5.9mm_P7.5mm

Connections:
01_ac_input/DLY: C101.1, R101.2, R102.1
01_ac_input/HL: BD101.2, CX102.1, CY101.1, LF101.2
01_ac_input/HN: BD101.3, CX102.2, CY102.1, LF101.4
01_ac_input/L: F101.1, J101.1, RV101.1
01_ac_input/LA: F101.2, K101.11, K101.21, RT101.1
01_ac_input/LC: CX101.1, K101.14, K101.24, LF101.1, RT101.2
01_ac_input/N: CX101.2, J101.2, LF101.3, RV101.2
01_ac_input/RLY_B: Q101.1 (B), R102.2, R103.1
01_ac_input/RLY_SW: K101.A2, Q101.3 (C)
+12V: K101.A1; also elsewhere on the board
+15V: R101.1; also elsewhere on the board
GND: BD101.4 (-), C101.2, Q101.2 (E), R103.2; also elsewhere on the board
GND48: CY101.2, CY102.2; also elsewhere on the board
VRECT: BD101.1 (+); also elsewhere on the board

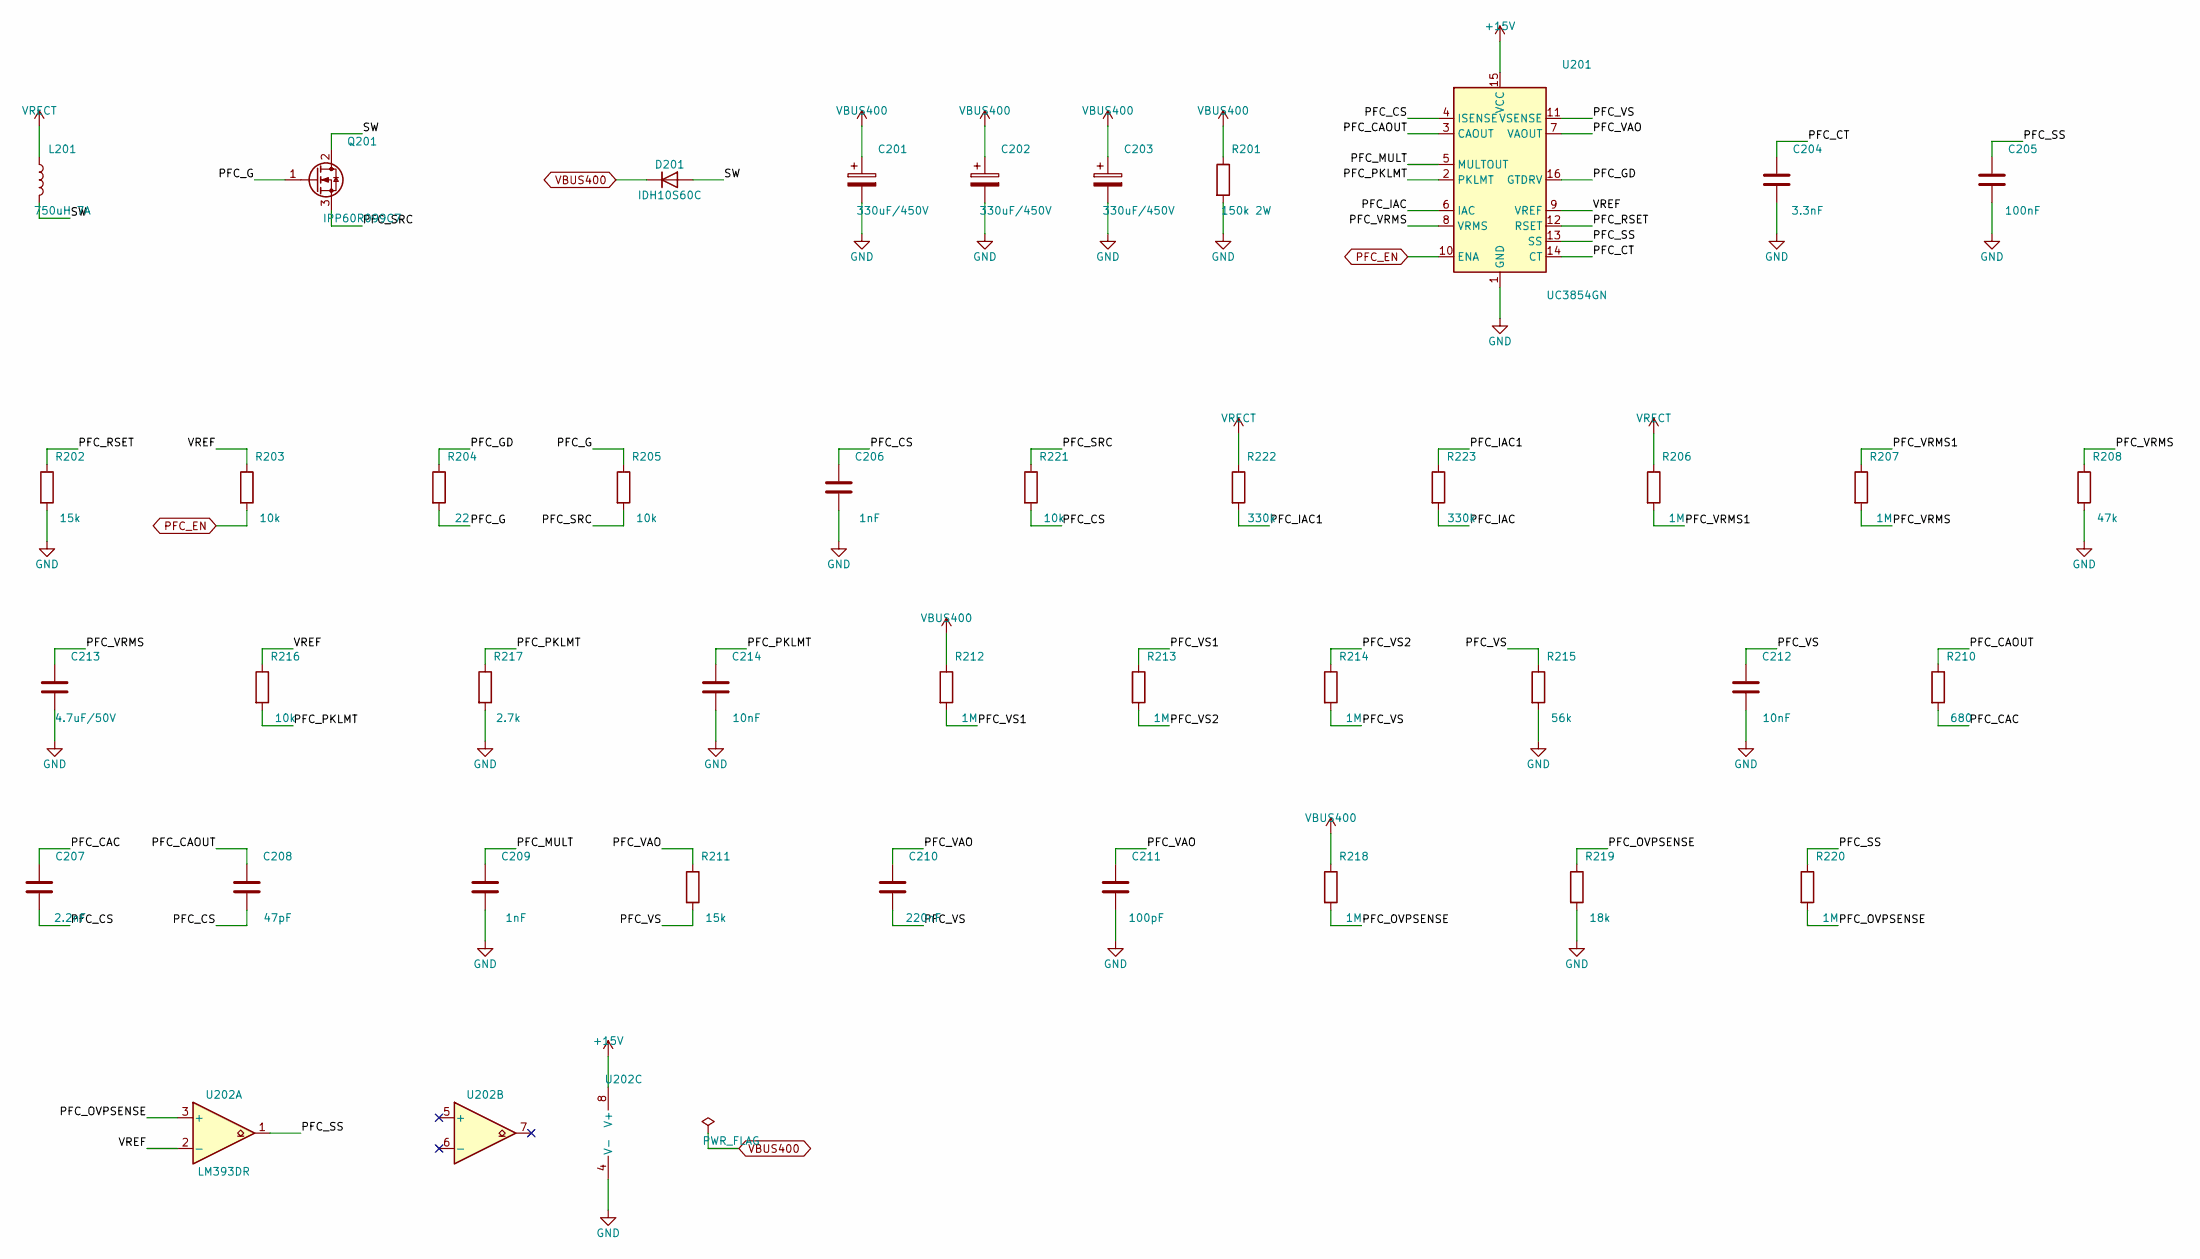
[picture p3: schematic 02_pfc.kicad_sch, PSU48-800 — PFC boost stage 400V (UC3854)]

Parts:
C201, C202, C203: 330uF/450V; CP_Radial_D35.0mm_P10.00mm
C204: 3.3nF; C_0805_2012Metric
C205: 100nF; C_0805_2012Metric
C206, C209: 1nF; C_0805_2012Metric
C207: 2.2nF; C_0805_2012Metric
C208: 47pF; C_0805_2012Metric
C210: 220nF; C_0805_2012Metric
C211: 100pF; C_0805_2012Metric
C212, C214: 10nF; C_0805_2012Metric
C213: 4.7uF/50V; C_1210_3225Metric
D201: IDH10S60C; TO-220-3_Vertical
L201: 750uH 7A; L_THT_D30.0mm_P15.00mm
Q201: IPP60R099C7; TO-220-3_Vertical
R201: 150k 2W; R_Axial_DIN0617_L17.0mm_D6.0mm_P25.40mm_Horizontal
R202, R211: 15k; R_0805_2012Metric
R203, R205, R216, R221: 10k; R_0805_2012Metric
R204: 22; R_0805_2012Metric
R206, R207, R212, R213, R214, R218: 1M; R_1206_3216Metric
R208: 47k; R_0805_2012Metric
R210: 680; R_0805_2012Metric
R215: 56k; R_0805_2012Metric
R217: 2.7k; R_0805_2012Metric
R219: 18k; R_0805_2012Metric
R220: 1M; R_0805_2012Metric
R222, R223: 330k; R_1206_3216Metric
U201: UC3854GN; DIP-16_W7.62mm
U202: LM393DR; SOIC-8_3.9x4.9mm_P1.27mm

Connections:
02_pfc/PFC_CAC: C207.1, R210.2
02_pfc/PFC_CAOUT: C208.1, R210.1, U201.3 (CAOUT)
02_pfc/PFC_CS: C206.1, C207.2, C208.2, R221.2, U201.4 (ISENSE)
02_pfc/PFC_CT: C204.1, U201.14 (CT)
02_pfc/PFC_G: Q201.1 (G), R204.2, R205.1
02_pfc/PFC_GD: R204.1, U201.16 (GTDRV)
02_pfc/PFC_IAC: R223.2, U201.6 (IAC)
02_pfc/PFC_IAC1: R222.2, R223.1
02_pfc/PFC_MULT: C209.1, U201.5 (MULTOUT)
02_pfc/PFC_OVPSENSE: R218.2, R219.1, R220.2, U202.3 (+)
02_pfc/PFC_PKLMT: C214.1, R216.2, R217.1, U201.2 (PKLMT)
02_pfc/PFC_RSET: R202.1, U201.12 (RSET)
02_pfc/PFC_SRC: Q201.3 (S), R205.2, R221.1
02_pfc/PFC_SS: C205.1, R220.1, U201.13 (SS), U202.1
02_pfc/PFC_VAO: C210.1, C211.1, R211.1, U201.7 (VAOUT)
02_pfc/PFC_VRMS: C213.1, R207.2, R208.1, U201.8 (VRMS)
02_pfc/PFC_VRMS1: R206.2, R207.1
02_pfc/PFC_VS: C210.2, C212.1, R211.2, R214.2, R215.1, U201.11 (VSENSE)
02_pfc/PFC_VS1: R212.2, R213.1
02_pfc/PFC_VS2: R213.2, R214.1
02_pfc/SW: D201.2 (A), L201.2, Q201.2 (D)
02_pfc/VREF: R203.1, R216.1, U201.9 (VREF), U202.2 (-)
+15V: U201.15 (VCC), U202.8 (V+); also elsewhere on the board
GND: C201.2, C202.2, C203.2, C204.2, C205.2, C206.2, C209.2, C211.2, C212.2, C213.2, C214.2, R201.2, R202.2, R208.2, R215.2, R217.2, R219.2, U201.1 (GND), U202.4 (V-); also elsewhere on the board
PFC_EN: R203.2, U201.10 (ENA); also elsewhere on the board
VBUS400: C201.1, C202.1, C203.1, D201.1 (K), R201.1, R212.1, R218.1; also elsewhere on the board
VRECT: L201.1, R206.1, R222.1; also elsewhere on the board

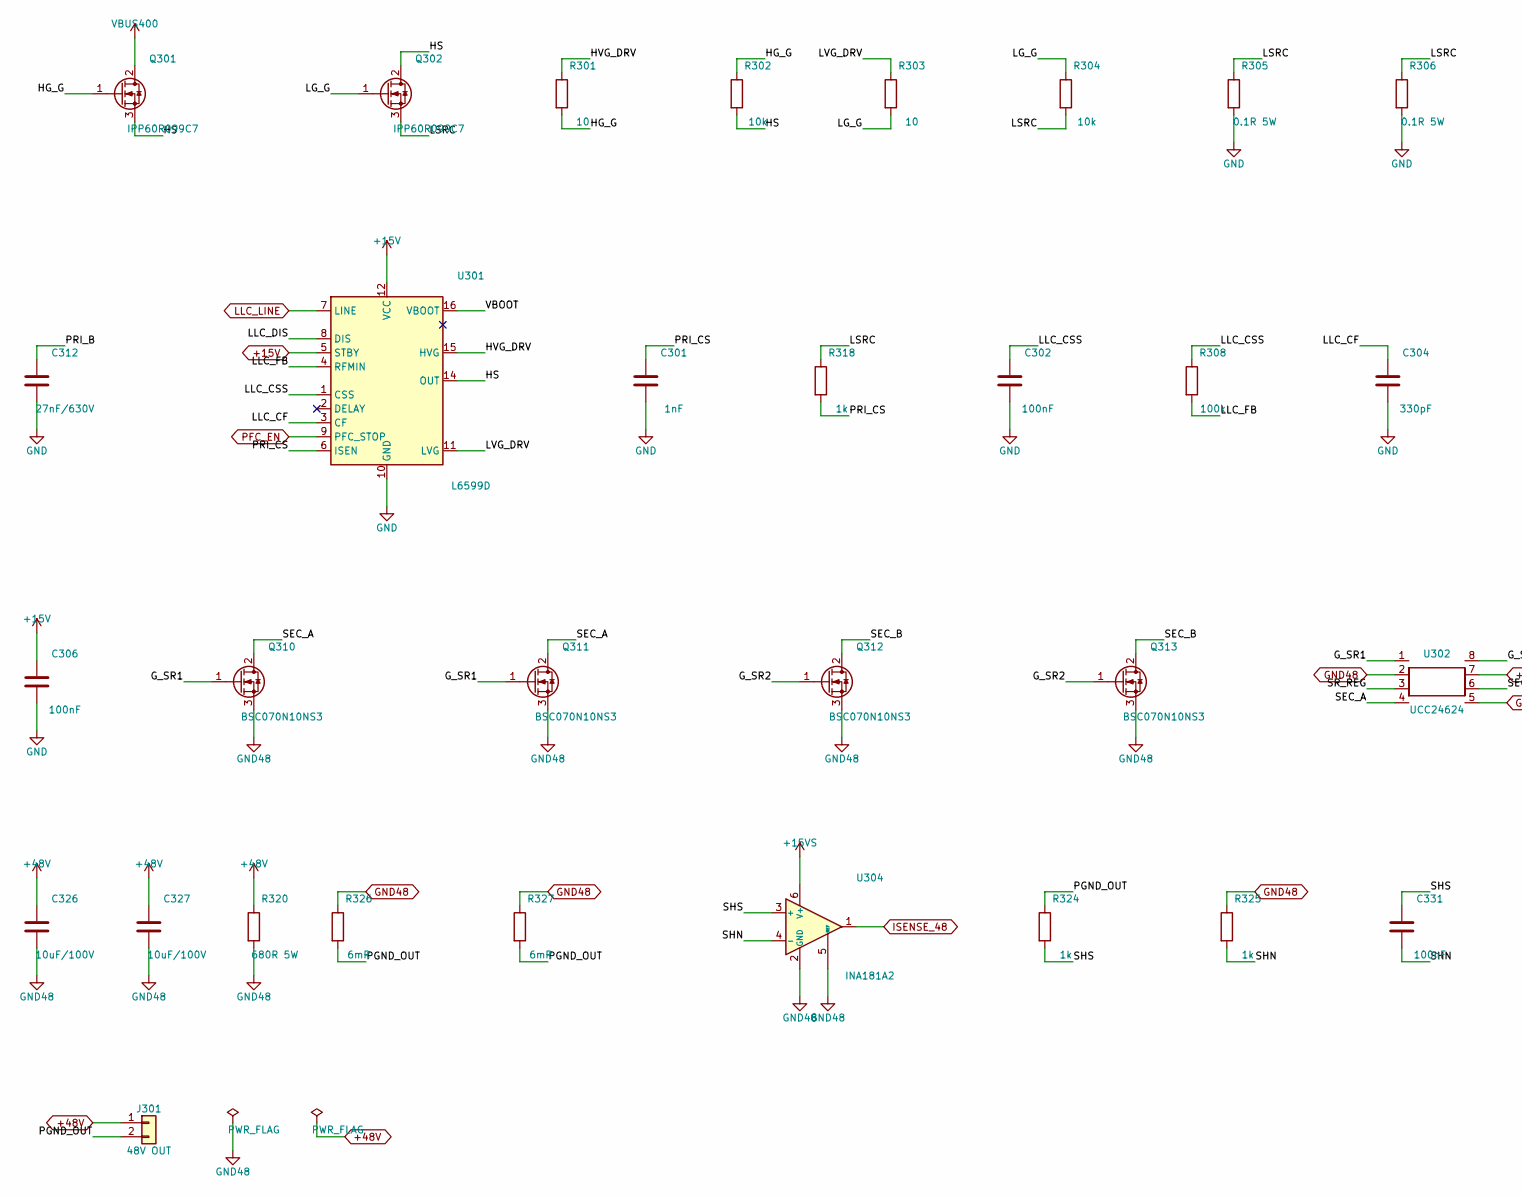
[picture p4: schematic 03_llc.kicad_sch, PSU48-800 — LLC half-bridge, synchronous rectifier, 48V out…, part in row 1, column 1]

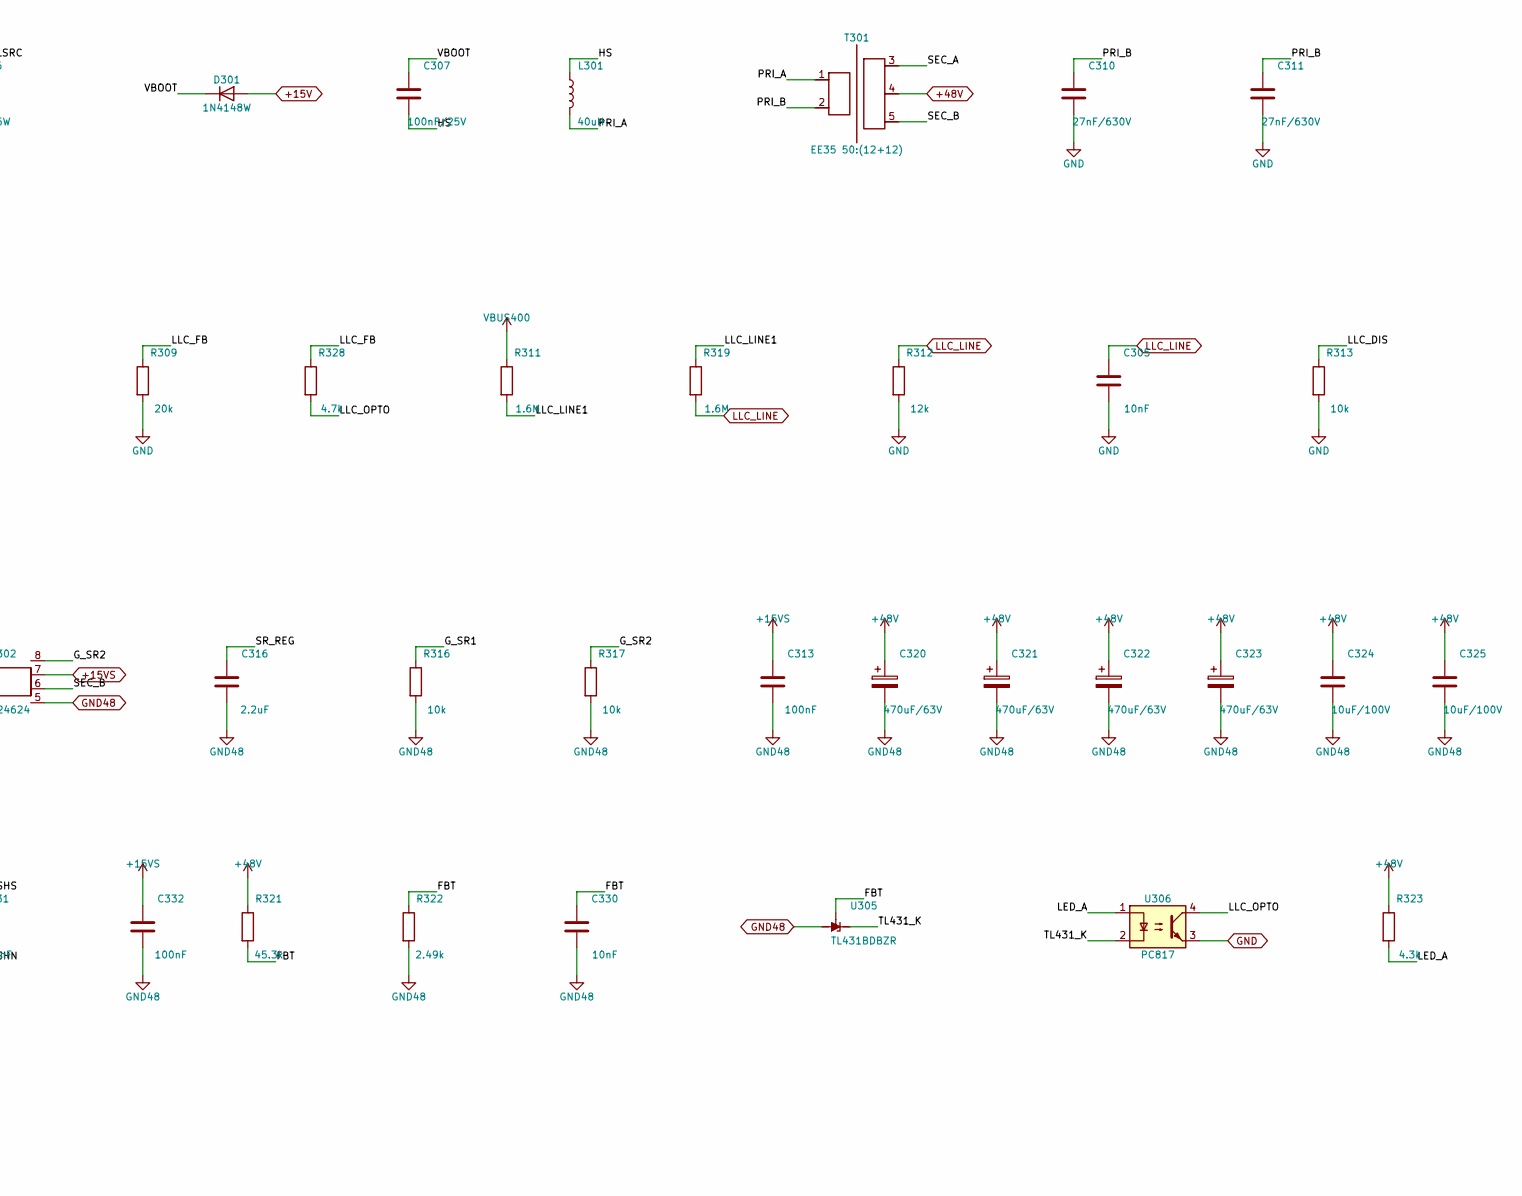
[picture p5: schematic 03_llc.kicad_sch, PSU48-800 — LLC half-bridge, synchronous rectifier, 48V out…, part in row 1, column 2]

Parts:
C301: 1nF; C_0805_2012Metric
C302, C306, C313, C331, C332: 100nF; C_0805_2012Metric
C304: 330pF; C_0805_2012Metric
C305, C330: 10nF; C_0805_2012Metric
C307: 100nF/25V; C_0805_2012Metric
C310, C311, C312: 27nF/630V; C_Rect_L16.5mm_W5.0mm_P15.00mm_MKT
C316: 2.2uF; C_0805_2012Metric
C320, C321, C322, C323: 470uF/63V; CP_Radial_D16.0mm_P7.50mm
C324, C325, C326, C327: 10uF/100V; C_1210_3225Metric
D301: 1N4148W; D_SOD-123
J301: 48V OUT; PinHeader_1x02_P2.54mm_Vertical
L301: 40uH; L_THT_25x20_P10.00mm
Q301, Q302: IPP60R099C7; TO-247-3_Vertical
Q310, Q311, Q312, Q313: BSC070N10NS3; PQFN-8-EP_6x5mm_P1.27mm_Generic
R301, R303: 10; R_0805_2012Metric
R302, R304, R313, R316, R317: 10k; R_0805_2012Metric
R305, R306: 0.1R 5W; R_Axial_DIN0617_L17.0mm_D6.0mm_P25.40mm_Horizontal
R308: 100k; R_0805_2012Metric
R309: 20k; R_0805_2012Metric
R311, R319: 1.6M; R_1206_3216Metric
R312: 12k; R_0805_2012Metric
R318, R324, R325: 1k; R_0805_2012Metric
R320: 680R 5W; R_Axial_DIN0617_L17.0mm_D6.0mm_P25.40mm_Horizontal
R321: 45.3k; R_0805_2012Metric
R322: 2.49k; R_0805_2012Metric
R323: 4.3k; R_0805_2012Metric
R326, R327: 6mR; R_2512_6332Metric
R328: 4.7k; R_0805_2012Metric
T301: EE35 50:(12+12); T_EE35_5pin_P5.00mm
U301: L6599D; SOIC-16_3.9x9.9mm_P1.27mm
U302: UCC24624; SOIC-8_3.9x4.9mm_P1.27mm
U304: INA181A2; SOT-23-5
U305: TL431BDBZR; SOT-23-5
U306: PC817; DIP-4_W7.62mm

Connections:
03_llc/FBT: C330.1, R321.2, R322.1, U305.4 (REF)
03_llc/G_SR1: Q310.1 (G), Q311.1 (G), R316.1, U302.1 (VG1)
03_llc/G_SR2: Q312.1 (G), Q313.1 (G), R317.1, U302.8 (VG2)
03_llc/HG_G: Q301.1 (G), R301.2, R302.1
03_llc/HS: C307.2, L301.1, Q301.3 (S), Q302.2 (D), R302.2, U301.14 (OUT)
03_llc/HVG_DRV: R301.1, U301.15 (HVG)
03_llc/LED_A: R323.2, U306.1
03_llc/LG_G: Q302.1 (G), R303.2, R304.1
03_llc/LLC_CF: C304.1, U301.3 (CF)
03_llc/LLC_CSS: C302.1, R308.1, U301.1 (CSS)
03_llc/LLC_DIS: R313.1, U301.8 (DIS)
03_llc/LLC_FB: R308.2, R309.1, R328.1, U301.4 (RFMIN)
03_llc/LLC_LINE1: R311.2, R319.1
03_llc/LLC_OPTO: R328.2, U306.4
03_llc/LSRC: Q302.3 (S), R304.2, R305.1, R306.1, R318.1
03_llc/LVG_DRV: R303.1, U301.11 (LVG)
03_llc/PGND_OUT: J301.2, R324.1, R326.2, R327.2
03_llc/PRI_A: L301.2, T301.1
03_llc/PRI_B: C310.1, C311.1, C312.1, T301.2
03_llc/PRI_CS: C301.1, R318.2, U301.6 (ISEN)
03_llc/SEC_A: Q310.2 (D), Q311.2 (D), T301.3, U302.4 (VD1)
03_llc/SEC_B: Q312.2 (D), Q313.2 (D), T301.5, U302.6 (VD2)
03_llc/SHN: C331.2, R325.2, U304.4 (-)
03_llc/SHS: C331.1, R324.2, U304.3 (+)
03_llc/SR_REG: C316.1, U302.3 (REG)
03_llc/TL431_K: U305.3 (K), U306.2
03_llc/VBOOT: C307.1, D301.1 (K), U301.16 (VBOOT)
+15V: C306.1, D301.2 (A), U301.5 (STBY), U301.12 (VCC); also elsewhere on the board
+15VS: C313.1, C332.1, U302.7 (VDD), U304.6 (V+); also elsewhere on the board
+48V: C320.1, C321.1, C322.1, C323.1, C324.1, C325.1, C326.1, C327.1, J301.1, R320.1, R321.1, R323.1, T301.4; also elsewhere on the board
GND: C301.2, C302.2, C304.2, C305.2, C306.2, C310.2, C311.2, C312.2, R305.2, R306.2, R309.2, R312.2, R313.2, U301.10 (GND), U306.3; also elsewhere on the board
GND48: C313.2, C316.2, C320.2, C321.2, C322.2, C323.2, C324.2, C325.2, C326.2, C327.2, C330.2, C332.2, Q310.3 (S), Q311.3 (S), Q312.3 (S), Q313.3 (S), R316.2, R317.2, R320.2, R322.2, R325.1, R326.1, R327.1, U302.2 (PGND), U302.5 (VSS), U304.2 (GND), U304.5 (REF), U305.5 (A); also elsewhere on the board
ISENSE_48: U304.1; also elsewhere on the board
LLC_LINE: C305.1, R312.1, R319.2, U301.7 (LINE); also elsewhere on the board
PFC_EN: U301.9 (PFC_STOP); also elsewhere on the board
VBUS400: Q301.2 (D), R311.1; also elsewhere on the board

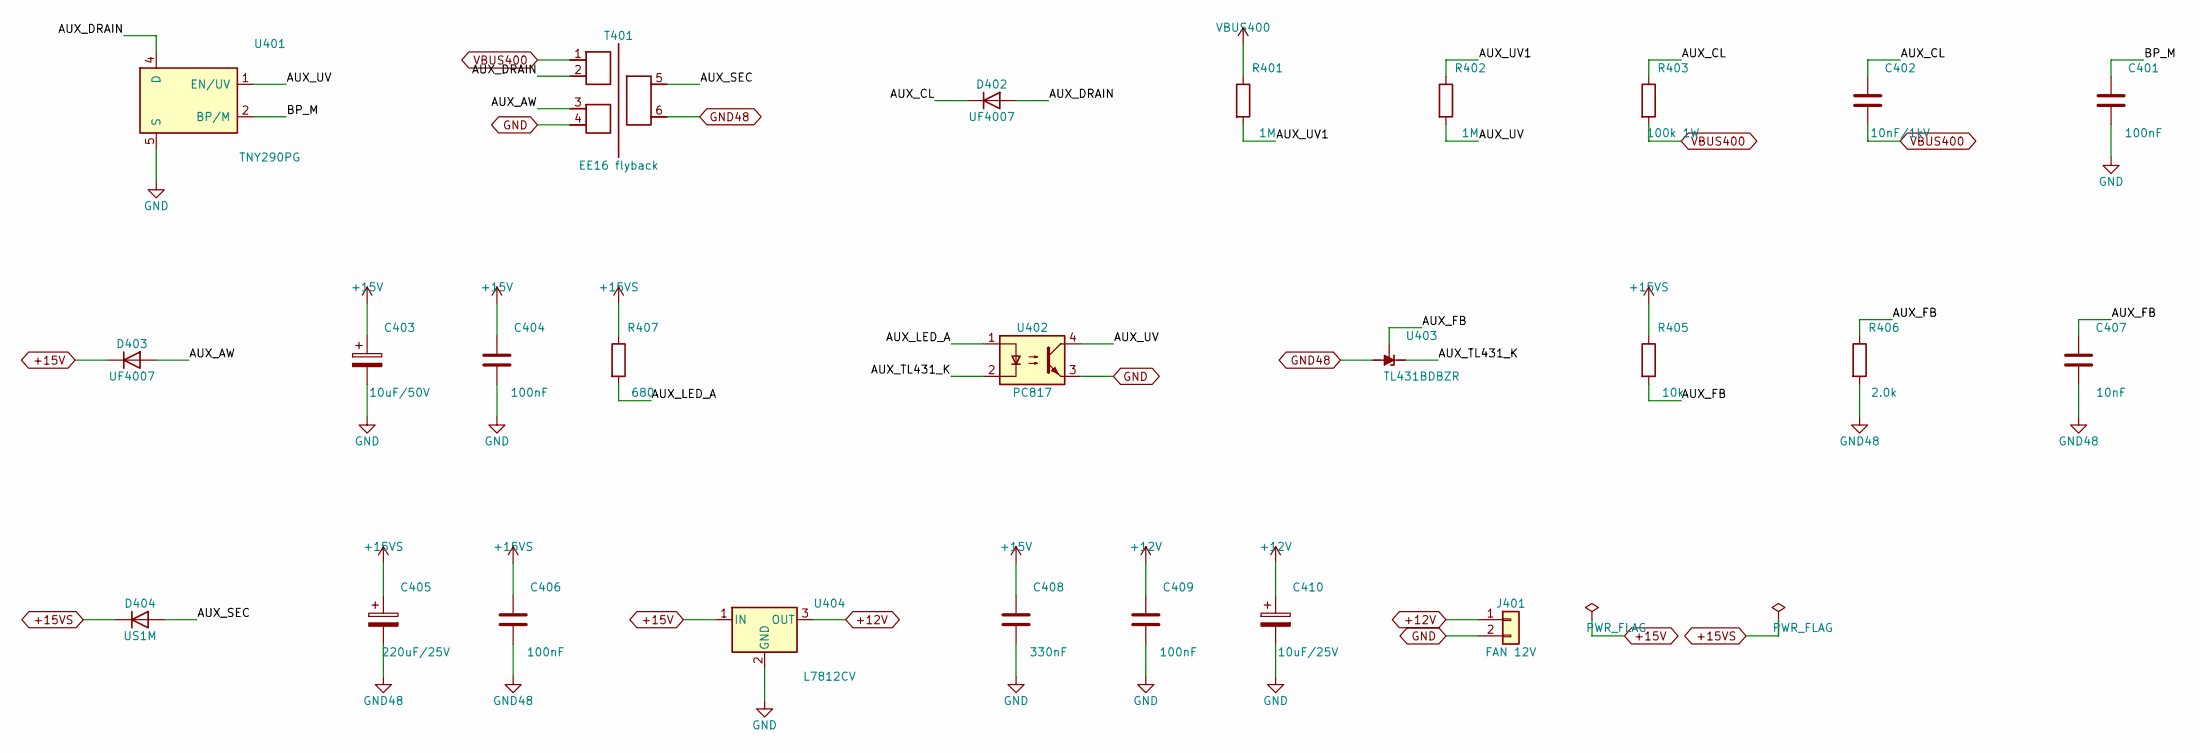
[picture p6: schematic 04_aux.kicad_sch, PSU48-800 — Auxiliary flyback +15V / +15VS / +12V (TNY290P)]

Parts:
C401, C404, C406, C409: 100nF; C_0805_2012Metric
C402: 10nF/1kV; C_Rect_L24.0mm_W10.1mm_P22.50mm_MKT
C403: 10uF/50V; CP_Radial_D5.0mm_P2.50mm
C405: 220uF/25V; CP_Radial_D10.0mm_P5.00mm
C407: 10nF; C_0805_2012Metric
C408: 330nF; C_0805_2012Metric
C410: 10uF/25V; CP_Radial_D5.0mm_P2.50mm
D402, D403: UF4007; D_DO-41_SOD81_P10.16mm_Horizontal
D404: US1M; D_SMA
J401: FAN 12V; PinHeader_1x02_P2.54mm_Vertical
R401, R402: 1M; R_1206_3216Metric
R403: 100k 1W; R_Axial_DIN0617_L17.0mm_D6.0mm_P25.40mm_Horizontal
R405: 10k; R_0805_2012Metric
R406: 2.0k; R_0805_2012Metric
R407: 680; R_0805_2012Metric
T401: EE16 flyback; T_EE16_6pin_P2.50mm
U401: TNY290PG; DIP-8_W7.62mm
U402: PC817; DIP-4_W7.62mm
U403: TL431BDBZR; SOT-23-5
U404: L7812CV; TO-220-3_Vertical

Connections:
04_aux/AUX_AW: D403.2 (A), T401.3
04_aux/AUX_CL: C402.1, D402.1 (K), R403.1
04_aux/AUX_DRAIN: D402.2 (A), T401.2, U401.4 (D)
04_aux/AUX_FB: C407.1, R405.2, R406.1, U403.4 (REF)
04_aux/AUX_LED_A: R407.2, U402.1
04_aux/AUX_SEC: D404.2 (A), T401.5
04_aux/AUX_TL431_K: U402.2, U403.3 (K)
04_aux/AUX_UV: R402.2, U401.1 (EN/UV), U402.4
04_aux/AUX_UV1: R401.2, R402.1
04_aux/BP_M: C401.1, U401.2 (BP/M)
+12V: C409.1, C410.1, J401.1, U404.3 (OUT); also elsewhere on the board
+15V: C403.1, C404.1, C408.1, D403.1 (K), U404.1 (IN); also elsewhere on the board
+15VS: C405.1, C406.1, D404.1 (K), R405.1, R407.1; also elsewhere on the board
GND: C401.2, C403.2, C404.2, C408.2, C409.2, C410.2, J401.2, T401.4, U401.5 (S), U401.6 (S), U401.7 (S), U401.8 (S), U402.3, U404.2 (GND); also elsewhere on the board
GND48: C405.2, C406.2, C407.2, R406.2, T401.6, U403.5 (A); also elsewhere on the board
VBUS400: C402.2, R401.1, R403.2, T401.1; also elsewhere on the board

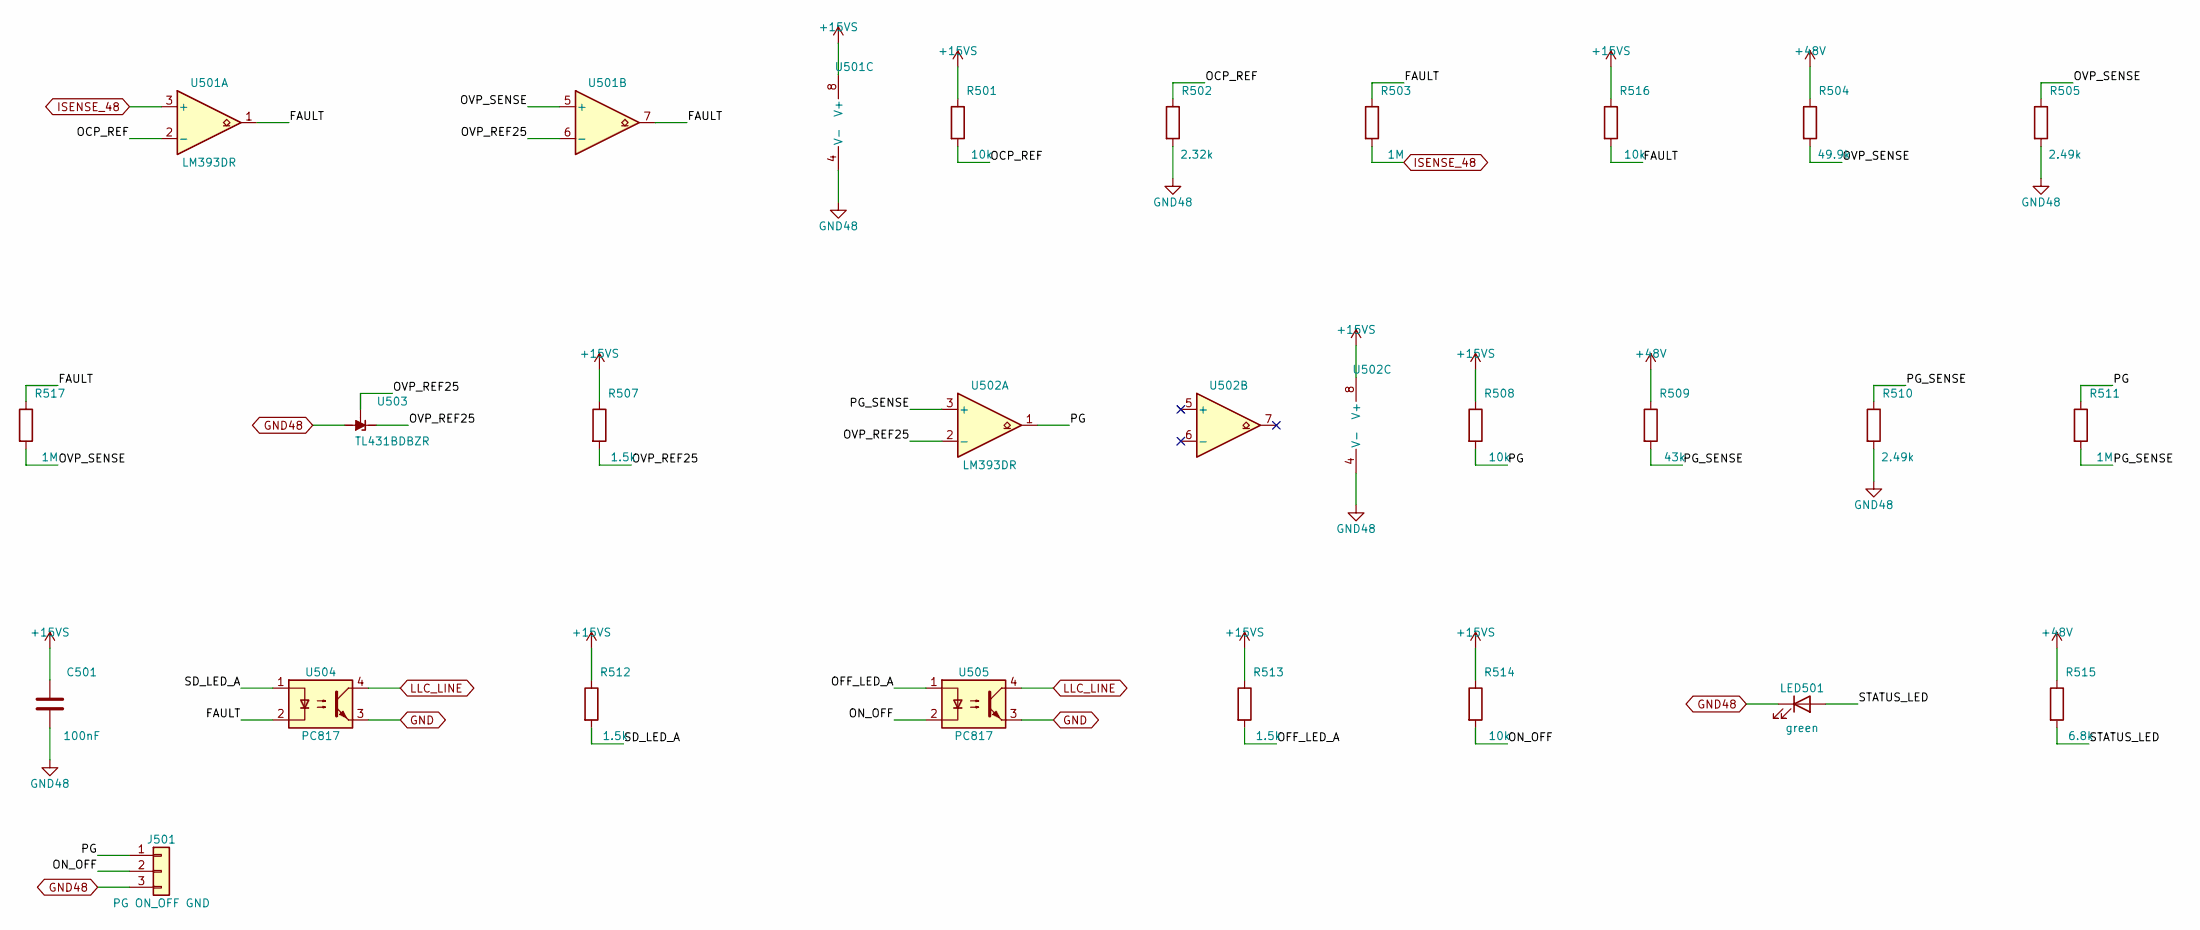
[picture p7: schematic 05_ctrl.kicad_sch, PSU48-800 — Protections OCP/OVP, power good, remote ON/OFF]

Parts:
C501: 100nF; C_0805_2012Metric
J501: PG ON_OFF GND; PinHeader_1x03_P2.54mm_Vertical
LED501: green; LED_0805_2012Metric
R501, R508, R514, R516: 10k; R_0805_2012Metric
R502: 2.32k; R_0805_2012Metric
R503, R511, R517: 1M; R_0805_2012Metric
R504: 49.9k; R_1206_3216Metric
R505, R510: 2.49k; R_0805_2012Metric
R507, R512, R513: 1.5k; R_0805_2012Metric
R509: 43k; R_1206_3216Metric
R515: 6.8k; R_0805_2012Metric
U501, U502: LM393DR; SOIC-8_3.9x4.9mm_P1.27mm
U503: TL431BDBZR; SOT-23-5
U504, U505: PC817; DIP-4_W7.62mm

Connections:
05_ctrl/FAULT: R503.1, R516.2, R517.1, U501.1, U501.7, U504.2
05_ctrl/OCP_REF: R501.2, R502.1, U501.2 (-)
05_ctrl/OFF_LED_A: R513.2, U505.1
05_ctrl/ON_OFF: J501.2, R514.2, U505.2
05_ctrl/OVP_REF25: R507.2, U501.6 (-), U502.2 (-), U503.3 (K), U503.4 (REF)
05_ctrl/OVP_SENSE: R504.2, R505.1, R517.2, U501.5 (+)
05_ctrl/PG: J501.1, R508.2, R511.1, U502.1
05_ctrl/PG_SENSE: R509.2, R510.1, R511.2, U502.3 (+)
05_ctrl/SD_LED_A: R512.2, U504.1
05_ctrl/STATUS_LED: LED501.2 (A), R515.2
+15VS: C501.1, R501.1, R507.1, R508.1, R512.1, R513.1, R514.1, R516.1, U501.8 (V+), U502.8 (V+); also elsewhere on the board
+48V: R504.1, R509.1, R515.1; also elsewhere on the board
GND: U504.3, U505.3; also elsewhere on the board
GND48: C501.2, J501.3, LED501.1 (K), R502.2, R505.2, R510.2, U501.4 (V-), U502.4 (V-), U503.5 (A); also elsewhere on the board
ISENSE_48: R503.2, U501.3 (+); also elsewhere on the board
LLC_LINE: U504.4, U505.4; also elsewhere on the board

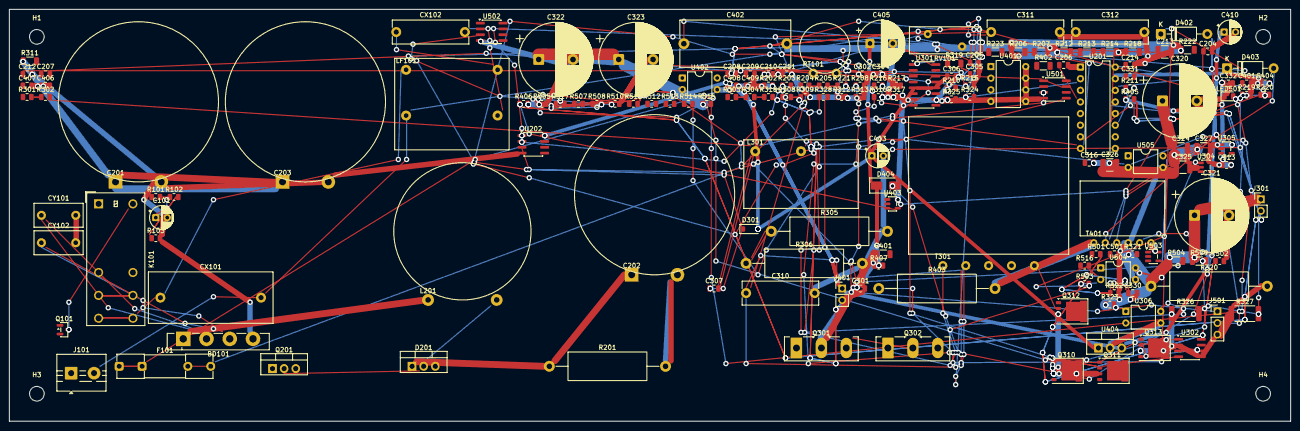
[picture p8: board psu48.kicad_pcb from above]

Board: 2 copper layers, 280.0 x 90.0 mm, 171 parts (0 on the bottom side), 89 nets.

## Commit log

2026-10-06 Инициализация проекта PSU48-800: ТЗ, расчёт топологии, инженерный журнал
    - Создан git-репозиторий, .gitignore для KiCad.
    - docs/SPEC.md: ТЗ на БП 220В->48В 800Вт, габариты платы 280x90 мм, высота 40 мм.
    - docs/DESIGN.md: выбор топологии (boost PFC 400В + LLC полумост 88кГц,
    синхронный выпрямитель, вспомогательный flyback TNY290), расчёт резонансного
    контура Lr=40мкГн/Cr=82нФ/Lm=160мкГн, баланс мощности и тепловой баланс.
    - JOURNAL.md: инженерный жу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
2026-10-06 Этап 2: инструменты генерации и библиотеки проекта
    - tools/sexp.py: парсер/сериализатор s-выражений KiCad; исправлена ошибка
    dumps() (токены заголовка печатались дважды) и добавлена защита от
    атомов после дочерних узлов.
    - tools/kilib.py: чтение .kicad_sym (extends, пины, единицы), геометрия
    выводов с трансформацией инстанса, встраивание символов в схему,
    проверка наличия footprint.
    - tools/dump_pins.py: дамп пинов симво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
2026-10-06 Этап 3: схема из 5 листов, генератор schgen, ERC=0, сверка нетлиста
    - sch_data.py: декларативная спецификация соединений (карты 'вывод→цепь')
    - schgen.py: генератор иерархической схемы (root A4 + листы A3/A2), терминаторы,
    L-изгибы, локальные/глобальные метки, PWR_FLAG, instance-пути, kicad_pro
    - verify.py: сверка netlist (kicad-cli) со спецификацией — 445 выводов/97 цепей OK
    - qa.py: геометрический контроль наложений текста/символов
    - kilib.py: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
    [01_ac_input.kicad_sch, 02_pfc.kicad_sch, 03_llc.kicad_sch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]
2026-10-06 Этап 3.1: уточнения по даташитам (L6599 RFmin/RFmax/Css, замена UCC24610→UCC24624)
    - websearch-верификация: L6599 RFmin — 2В источник, ветви RFmin/RFmax/Css-Rss,
    полярность ОС подтверждена (ток↑→частота↑→Vout↓); пин 2/13 N.C.
    - UCC24610 не применим: VD макс 50В против ~96В на стоке SR при 48В выходе;
    SYNC к GND удерживал бы GATE выкл.
    - Добавлен символ psu48_lib:UCC24624 (SOIC-8, VT до 230В, 2 канала)
    - Схема 03: 1×UCC24624 вместо 2×UCC24610; R328 4.7k RFmax; R308 мягкий старт;
    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
    [03_llc.kicad_sch, 04_aux.kicad_sch, 05_ctrl.kicad_sch]
2026-10-06 chore: исключить session/ (opencode session logs) из репозитория
2026-10-06 docs: референсные даташиты (+L6599A копия, UCC24624/10, UC3854, TinySwitch-4, INA181, LM393) в docs/datasheets/ с индексом
2026-10-07 Этап 4: генерация PCB (pcbgen: 167 корпусов + 4 отверстия), размещение, DRC без ошибок; правки схемы (SEC_A->AUX_SEC, LED_A->STATUS_LED)
    [03_llc.kicad_sch, 04_aux.kicad_sch, 05_ctrl.kicad_sch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]
2026-10-07 Этап 5 (черновик): автотрассировка router.py — валидный вывод для KiCad 10 ((net <code>)+uuid), 712 треков/595 виа; диагноз DRC (co-located vias, асимметричный зазор ширин); журнал
    [psu48.kicad_pcb]
2026-10-07 docs: руководство по переиспользованию tools/ в других проектах (порядок, адаптация, ограничения)
